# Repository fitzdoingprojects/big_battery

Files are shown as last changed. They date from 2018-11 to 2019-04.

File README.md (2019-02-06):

# big_battery
Charge Controller for 12 cell Lifepo4 batteries

Output voltage can be adjusted between 0 and 110% with voltage between TRM and -S on CN1:
Output Voltage = (Voltage between TMR and -S / 2.5) * 5V

Output current can be measured between CB adn -S on either CN1 or CN2.
Ouput current: 1Vcb = 0A, 0Vcb = 50A, -1Vcb = 100A
	Iout = 50 * (-Vcb + 1)
Required input impedance > 500kOh
Max current 120A ???

Circuit:
	Set TRM to default ouput of 4.2V, allow output range of 0 to 4.2V
	Invert and shift current sense from -1 to 2V, to 0V to 2.4V
	Over current feedback, with max current and trickle current
	Isolated signalling, either capacitive or dedicated IC

TESTING:
	* Double check default output voltage of 4.2V
	* Double check current graph/equation

Results:
    With 0 current, CB measuers 1.221V
    1A , 1.5V
    2A, 1.13
	3A, 1.098
	4A, 1.069
	5A, 1.04
SHOULD REQUIRE DIRECT TURN OFF?

BOARD REVISION:
 * ADD 3.3V test point
 * ADD potentiometer for adjusting current and voltage set points
 * change plus and minus inputs on op-amp B (because CB voltage decreases as voltage rises)
 * add reverse input protection diode
 * make sure trickle disable is pulled low
 * add some leds for signalling

 HOW FLASH EFM8 MCU:
 
 https://www.silabs.com/community/mcu/8-bit/knowledge-base.entry.html/2015/06/08/how_to_use_efm8_star-8aHu
 https://www.allaboutcircuits.com/projects/custom-pcb-design-with-an-efm8-microcontroller/

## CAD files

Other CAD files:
firmware/big_battery/Keil 8051 v9.53 - Debug/src/big_battery_main.OBJ
firmware/big_battery/Keil 8051 v9.53 - Debug/src/InitDevice.OBJ
mech/battery_terminal.SLDPRT
mech/power_supply_base.SLDPRT
firmware/big_battery/Keil 8051 v9.53 - Debug/src/SILABS_STARTUP.OBJ
mech/battery_terminal.DXF
mech/power_supply_base.DXF

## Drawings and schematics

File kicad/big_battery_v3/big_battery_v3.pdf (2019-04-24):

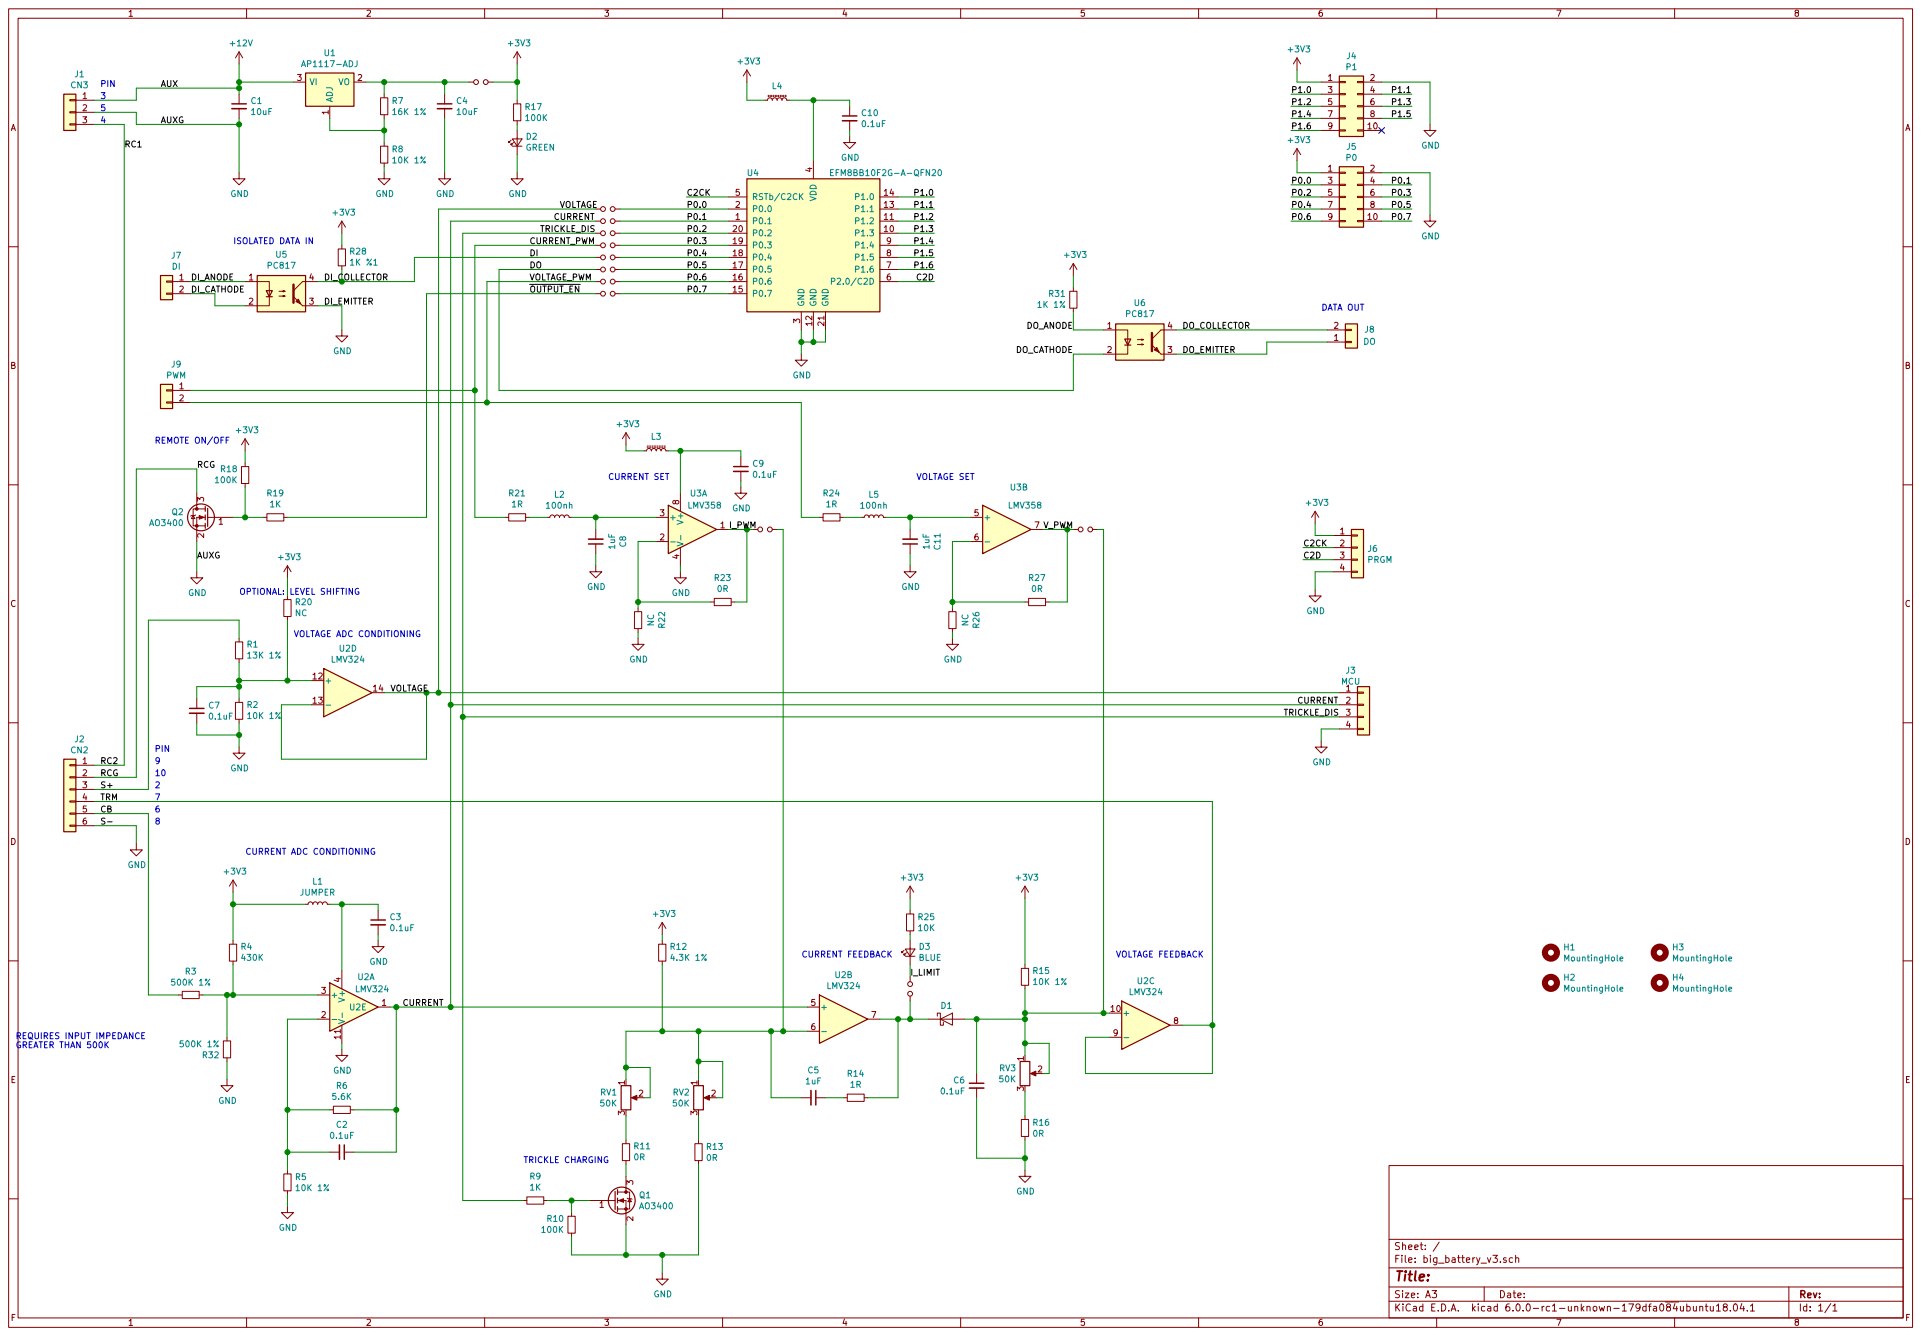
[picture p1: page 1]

J9 PWM
REMOTE ON/OFF PIN
100K GND

TRICKLE_DIS 3

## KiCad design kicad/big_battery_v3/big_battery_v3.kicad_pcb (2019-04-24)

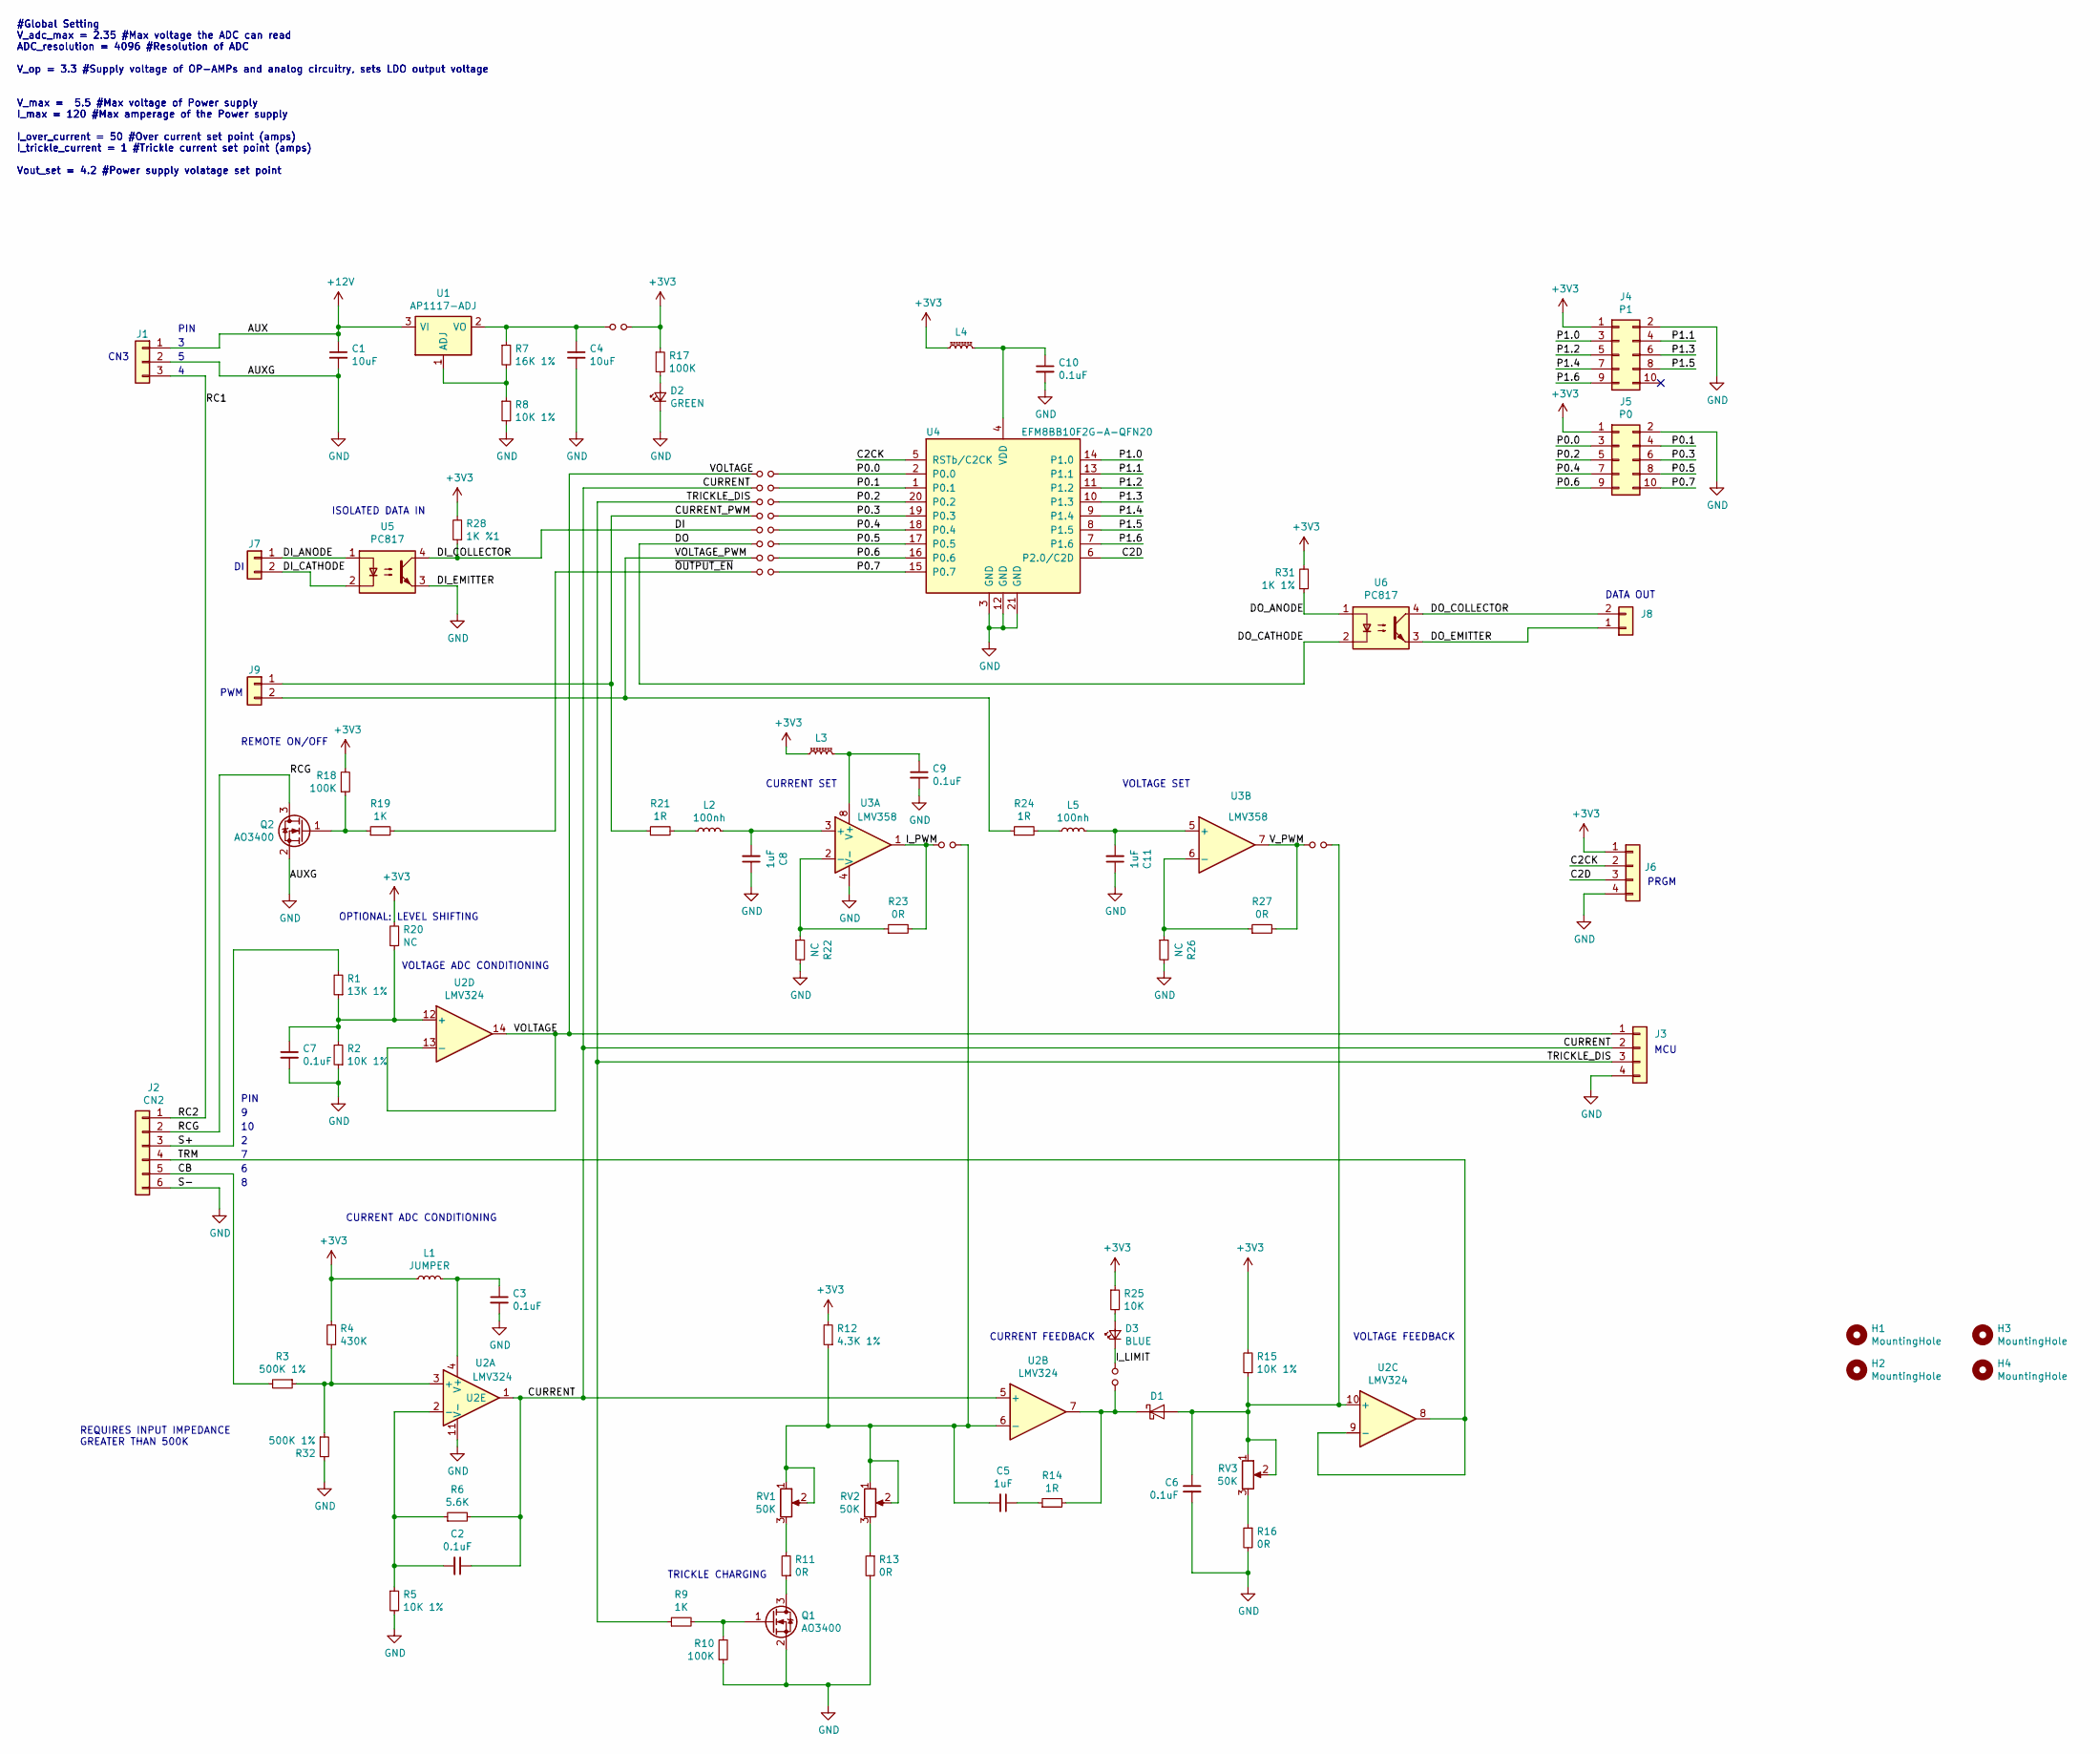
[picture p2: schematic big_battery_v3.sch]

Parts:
C1, C4: 10uF; C_0603_1608Metric_Pad1.05x0.95mm_HandSolder
C2, C3, C6, C7, C9, C10: 0.1uF; C_0603_1608Metric_Pad1.05x0.95mm_HandSolder
C5, C8, C11: 1uF; C_0603_1608Metric_Pad1.05x0.95mm_HandSolder
D1: D_Schottky_Small; D_SOD-323_HandSoldering
D2: GREEN; LED_0603_1608Metric_Pad1.05x0.95mm_HandSolder
D3: BLUE; LED_0603_1608Metric_Pad1.05x0.95mm_HandSolder
H1, H2, H3, H4: MountingHole; MountingHole_2.2mm_M2
J1: CONN; JST_EH_B03B-EH-A_1x03_P2.50mm_Vertical
J2: CN2; JST_EH_B06B-EH-A_1x06_P2.50mm_Vertical
J3, J6: CONN; JST_EH_B04B-EH-A_1x04_P2.50mm_Vertical
J4: P1; Multicomp_MC9A12-1034_2x05_P2.54mm_Vertical
J5: P0; Multicomp_MC9A12-1034_2x05_P2.54mm_Vertical
J7, J8, J9: CONN; JST_EH_B02B-EH-A_1x02_P2.50mm_Vertical
JP1, JP2, JP3, JP4, JP5, JP6, JP7, JP8, JP9, JP10, JP11, JP12: Jumper_NO_Small; SolderJumper-2_P1.3mm_Open_RoundedPad1.0x1.5mm
L1: JUMPER; L_0603_1608Metric_Pad1.05x0.95mm_HandSolder
L2, L5: 100nh; L_0603_1608Metric_Pad1.05x0.95mm_HandSolder
L3, L4: L_Core_Ferrite_Small; L_0603_1608Metric_Pad1.05x0.95mm_HandSolder
Q1, Q2: AO3400; SOT-23_Handsoldering
R1: 13K 1%; R_0603_1608Metric_Pad1.05x0.95mm_HandSolder
R2, R5, R8, R15: 10K 1%; R_0603_1608Metric_Pad1.05x0.95mm_HandSolder
R3, R32: 500K 1%; R_0603_1608Metric_Pad1.05x0.95mm_HandSolder
R4: 430K; R_0603_1608Metric_Pad1.05x0.95mm_HandSolder
R6: 5.6K; R_0603_1608Metric_Pad1.05x0.95mm_HandSolder
R7: 16K 1%; R_0603_1608Metric_Pad1.05x0.95mm_HandSolder
R9, R19: 1K; R_0603_1608Metric_Pad1.05x0.95mm_HandSolder
R10, R17, R18: 100K; R_0603_1608Metric_Pad1.05x0.95mm_HandSolder
R11, R13, R16, R23, R27: 0R; R_0603_1608Metric_Pad1.05x0.95mm_HandSolder
R12: 4.3K 1%; R_0603_1608Metric_Pad1.05x0.95mm_HandSolder
R14, R21, R24: 1R; R_0603_1608Metric_Pad1.05x0.95mm_HandSolder
R20, R22, R26: NC; R_0603_1608Metric_Pad1.05x0.95mm_HandSolder
R25: 10K; R_0603_1608Metric_Pad1.05x0.95mm_HandSolder
R28: 1K %1; R_0603_1608Metric_Pad1.05x0.95mm_HandSolder
R31: 1K 1%; R_0603_1608Metric_Pad1.05x0.95mm_HandSolder
RV1, RV2, RV3: 50K; Potentiometer_Bourns_3296W_Vertical
U1: AP1117-ADJ; SOT-223-3_TabPin2
U2: LMV324; SOIC-14_3.9x8.7mm_P1.27mm
U3: LMV358; SOIC-8_3.9x4.9mm_P1.27mm
U4: EFM8BB10F2G-A-QFN20; SiliconLabs_QFN-20-1EP_3x3mm_P0.5mm_ThermalVias
U5, U6: PC817; DIP-4_W7.62mm

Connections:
+3V3: J4.1, J5.1, J6.1, JP1.2, L1.1, L3.1, L4.1, R4.2, R12.2, R15.2, R17.1, R18.2, R20.2, R25.1, R28.2, R31.2
+12V: C1.1, J1.1, U1.3 (VI)
/C2CK: J6.2, U4.5 (RSTb/C2CK)
/C2D: J6.3, U4.6 (P2.0/C2D)
/CB: J2.5, R3.2
/CURRENT: C2.1, J3.2, JP3.1, R6.2, U2.1, U2.5 (+)
/CURRENT_PWM: J9.1, JP5.1, R21.1
/DI: JP6.1, R28.1, U5.4
/DI_ANODE: J7.1, U5.1
/DI_CATHODE: J7.2, U5.2
/DO: JP7.1, U6.2
/DO_ANODE: R31.1, U6.1
/DO_COLLECTOR: J8.2, U6.4
/DO_EMITTER: J8.1, U6.3
/I_LIMIT: D3.1 (K), JP9.2
/I_PWM: JP8.1, R23.2, U3.1
/P0.0: J5.3, JP2.2, U4.2 (P0.0)
/P0.1: J5.4, JP3.2, U4.1 (P0.1)
/P0.2: J5.5, JP4.2, U4.20 (P0.2)
/P0.3: J5.6, JP5.2, U4.19 (P0.3)
/P0.4: J5.7, JP6.2, U4.18 (P0.4)
/P0.5: J5.8, JP7.2, U4.17 (P0.5)
/P0.6: J5.9, JP11.2, U4.16 (P0.6)
/P0.7: J5.10, JP12.2, U4.15 (P0.7)
/P1.0: J4.3, U4.14 (P1.0)
/P1.1: J4.4, U4.13 (P1.1)
/P1.2: J4.5, U4.11 (P1.2)
/P1.3: J4.6, U4.10 (P1.3)
/P1.4: J4.7, U4.9 (P1.4)
/P1.5: J4.8, U4.8 (P1.5)
/P1.6: J4.9, U4.7 (P1.6)
/RC1: J1.3, J2.1
/RCG: J2.2, Q2.3 (D)
/S+: J2.3, R1.2
/TRICKLE_DIS: J3.3, JP4.1, R9.1
/TRM: J2.4, U2.8, U2.9 (-)
/VOLTAGE: J3.1, JP2.1, U2.13 (-), U2.14
/VOLTAGE_PWM: J9.2, JP11.1, R24.1
/V_PWM: JP10.1, R27.2, U3.7
/~OUTPUT_EN: JP12.1, R19.2
GND: C1.2, C3.2, C4.2, C6.2, C7.2, C8.1, C9.2, C10.2, C11.1, D2.1 (K), J1.2, J2.6, J3.4, J4.2, J5.2, J6.4, Q1.2 (S), Q2.2 (S), R2.1, R5.2, R8.2, R10.1, R13.2, R16.2, R22.2, R26.2, R32.2, U2.11 (V-), U3.4 (V-), U4.3 (GND), U4.12 (GND), U4.21 (GND), U5.3
unnamed: C2.2, R5.1, R6.1, U2.2 (-)
unnamed: C3.1, L1.2, U2.4 (V+)
unnamed: C4.1, JP1.1, R7.1, U1.2 (VO)
unnamed: C5.1, R14.1
unnamed: C5.2, JP8.2, R12.1, RV1.1, RV1.2, RV2.1, RV2.2, U2.6 (-)
unnamed: C6.1, D1.2 (A), JP10.2, R15.1, RV3.1, RV3.2, U2.10 (+)
unnamed: C7.1, R1.1, R2.2, R20.1, U2.12 (+)
unnamed: C8.2, L2.2, U3.3 (+)
unnamed: C9.1, L3.2, U3.8 (V+)
unnamed: C10.1, L4.2, U4.4 (VDD)
unnamed: C11.2, L5.2, U3.5 (+)
unnamed: D1.1 (K), JP9.1, R14.2, U2.7
unnamed: D2.2 (A), R17.2
unnamed: D3.2 (A), R25.2
unnamed: L2.1, R21.2
unnamed: L5.1, R24.2
unnamed: Q1.1 (G), R9.2, R10.2
unnamed: Q1.3 (D), R11.1
unnamed: Q2.1 (G), R18.1, R19.1
unnamed: R3.1, R4.1, R32.1, U2.3 (+)
unnamed: R7.2, R8.1, U1.1 (ADJ)
unnamed: R11.2, RV1.3
unnamed: R13.1, RV2.3
unnamed: R16.1, RV3.3
unnamed: R22.1, R23.1, U3.2 (-)
unnamed: R26.1, R27.1, U3.6 (-)

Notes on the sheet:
REQUIRES INPUT IMPEDANCE GREATER THAN 500K
#Global Setting V_adc_max = 2.35 #Max voltage the ADC can read ADC_resolution = 4096 #Resolution of ADC V_op = 3.3 #Supply voltage of OP-AMPs and analog circuitry, sets LDO output voltage V_max = 5.5 #Max voltage of Power supply I_max = 120 #Max amperage of the Power supply I_over_current = 50 #Ove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
OPTIONAL: LEVEL SHIFTING
CURRENT SET
VOLTAGE SET
VOLTAGE ADC CONDITIONING
CURRENT ADC CONDITIONING
CURRENT FEEDBACK
VOLTAGE FEEDBACK
TRICKLE CHARGING
ISOLATED DATA IN
REMOTE ON/OFF
PIN
DATA OUT
CN3
PWM
PRGM
MCU

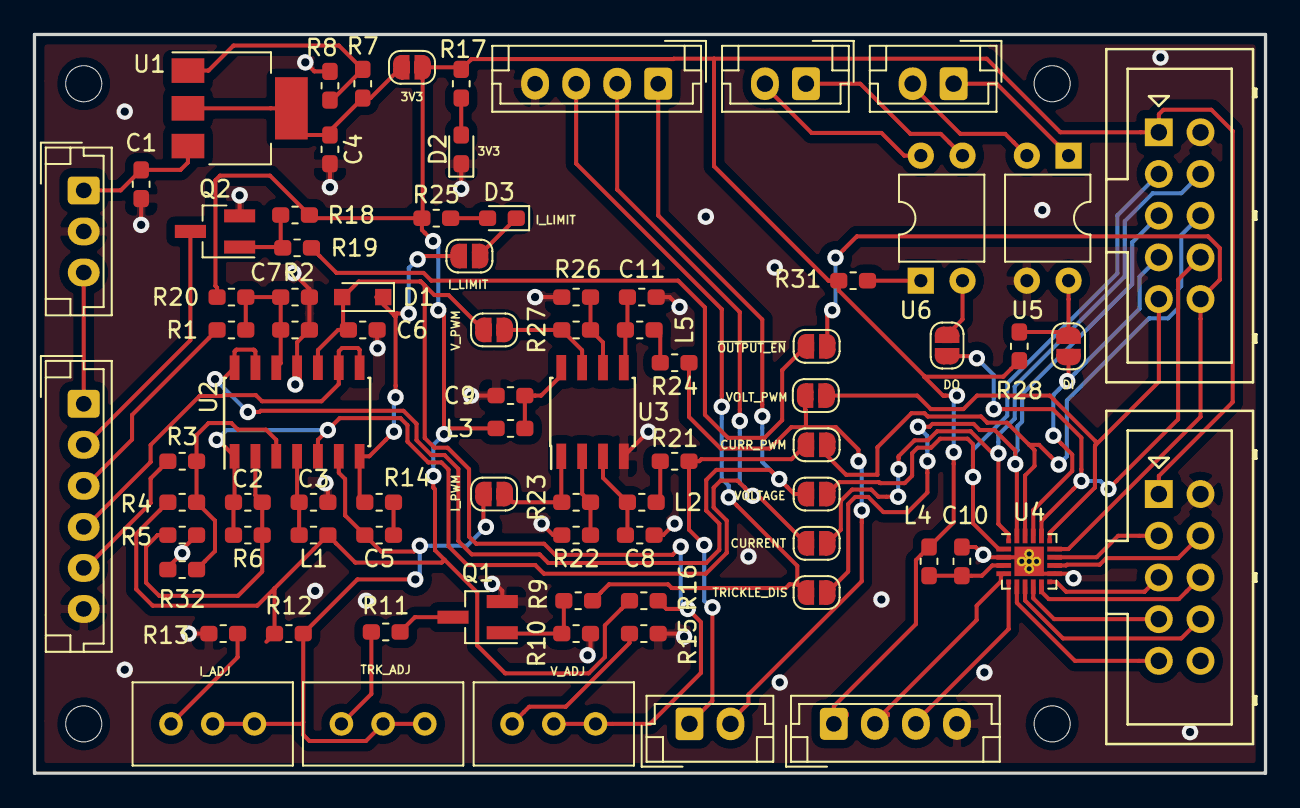
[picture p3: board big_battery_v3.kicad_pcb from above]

Board: 2 copper layers, 75.0 x 45.0 mm, 85 parts (0 on the bottom side), 67 nets.

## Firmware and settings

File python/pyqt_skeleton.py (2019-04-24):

import sys, time, serial
from struct import pack, unpack
import threading
from PyQt5 import QtCore, QtGui, QtWidgets
from test1 import Ui_Form
 
class MyFirstGuiProgram(Ui_Form):
    def __init__(self, dialog, comm):
        Ui_Form.__init__(self)
        self.setupUi(dialog)
        self.comm = comm
        self.connectButton.clicked.connect(self.connect)
        self.voltageButton.clicked.connect(self.setVoltage)
        self.voltageSlider.valueChanged.connect(self.convertVoltage)
        self.currentButton.clicked.connect(self.setCurrent)
        self.currentSlider.valueChanged.connect(self.convertCurrent)
        self.tricklecheckBox.stateChanged.connect(self.trickle)
        self.outputcheckBox.stateChanged.connect(self.output)
        self.pollButton.clicked.connect(self.poll)

    def connect(self):
        if not self.comm.connected:
            if(self.comm.open(self.seriallineEdit.text())):
                self.connected = True
                self.seriallineEdit.setEnabled(False)
                self.connectButton.setText("DISCONNECT")
                self.voltageButton.setEnabled(True)
                self.voltagelineEdit.setEnabled(True)
                self.currentButton.setEnabled(True)
                self.currentlineEdit.setEnabled(True)
                self.tricklecheckBox.setEnabled(True)
                self.outputcheckBox.setEnabled(True)
                self.pollButton.setEnabled(True)
                self.currentButton.setEnabled(True)
                self.currentButton.setEnabled(True)
                self.comHistory.appendPlainText("Connected: " + self.comm.dev)
            else:
                self.connectButton.setText("CONNECT")
                self.comHistory.appendPlainText("Failed to open: " + self.comm.dev)
        else:
            self.comm.close()
            self.connectButton.setText("CONNECT")
            self.seriallineEdit.setEnabled(True)
            self.voltageButton.setEnabled(False)
            self.voltagelineEdit.setEnabled(False)
            self.currentButton.setEnabled(False)
            self.currentlineEdit.setEnabled(False)
            self.tricklecheckBox.setEnabled(False)
            self.outputcheckBox.setEnabled(False)
            self.pollButton.setEnabled(False)
            self.currentButton.setEnabled(False)
            self.currentButton.setEnabled(False)
            self.comHistory.appendPlainText("Disconnected")
        
    def setVoltage(self):
        setV = self.voltagespinBox.value()
        cmd, out = self.comm.setVoltage('1', setV)
        self.updateCommandLine(cmd, out)
        
    def convertVoltage(self, val):
        self.voltagelineEdit.setText(str(val))

    def setCurrent(self):
        setC = self.currentSpinBox.value()
        cmd, out = self.comm.setCurrent('1', setC)
        self.updateCommandLine(cmd, out)

    def convertCurrent(self, val):
            self.currentlineEdit.setText(str(val))

    def trickle(self, state):
        cmd, out = self.comm.setTrickle('1', 1 if state else 0)
        self.updateCommandLine(cmd, out)

    def output(self, state):
        cmd, out = self.comm.setEnable('1', 1 if state else 0)
        self.updateCommandLine(cmd, out)

    def poll(self):
        cmd, out = self.comm.getVoltage('1')
        self.updateCommandLine(cmd, out)
        if out is not None:
            self.vadclineEdit.setText(str(out[2] * 0.0013195800781249998))
            self.vadclcdNumber.display(hex(out[2]))
        
        cmd, out = self.comm.getCurrent('1')
        self.updateCommandLine(cmd, out)
        if out is not None:
            self.iadclineEdit.setText(str((out[2] * -0.05815991633124628) + 240.93023255813955))
            self.iadclcdNumber.display(hex(out[2]))

        cmd, out = self.comm.getTemperature('1')
        self.updateCommandLine(cmd, out)
        if out is not None:
            self.tadclineEdit.setText(str(out[2]))
            self.tadclcdNumber.display(hex(out[2]))

    def updateCommandLine(self, cmd, out):
        self.comHistory.appendPlainText(">> " + str(cmd))
        self.comHistory.appendPlainText("<< " + str(out))

class BigBatteryComm():
    def __init__(self):
        self.connected = False

    def open(self, dev):
        self.dev = dev
        try:
            self.ser = serial.Serial(dev, 4800, timeout = 1) # ttyACM1 for Arduino board
            self.connected = True
            return True
        except:
            self.connected = False
            return False

    def close(self):
        self.connected = False
        self.ser.close()

    def setVoltage(self, devNum, val):
        return self.setVal(devNum, "TV", val)

    def setCurrent(self, devNum, val):
        return self.setVal(devNum, "TI", val)

    def setTrickle(self, devNum, val):
        return self.setVal(devNum, "TT", val)
    
    def setEnable(self, devNum, val):
        return self.setVal(devNum, "TE", val)

    def setVal(self, devNum, command , val):
        sent =  bytes(devNum, 'utf-8'), bytes(command, 'utf-8'), int(val), bytes('X', 'utf-8')
        cmd = pack('>c2sHc', bytes(devNum, 'utf-8'), bytes(command, 'utf-8'), int(val), bytes('X', 'utf-8'))
        try: 
            self.ser.write(cmd)
            out = self.ser.read(7)
            out = unpack('>ccH3s', out)
            self.ser.flush() #flush the buffer
        except:
            out = None
        return sent, out

    def getVoltage(self, devNum):
        return self.getVal(devNum, "RV")

    def getCurrent(self, devNum):
        return self.getVal(devNum, "RI")

    def getTemperature(self, devNum):
        return self.getVal(devNum, "RT")

    def getVal(self, devNum, command):
        sent = (bytes(devNum, 'utf-8'), bytes(command, 'utf-8'), bytes('X', 'utf-8'))
        cmd = pack('c2sc', bytes(devNum, 'utf-8'), bytes(command, 'utf-8'), bytes('X', 'utf-8'))
        try: 
            self.ser.write(cmd)
            out = self.ser.read(7)
            out = unpack('>ccH3s', out)
            print(out)
            self.ser.flush() #flush the buffer
        except:
            out = None
        return sent, out

    




if __name__ == '__main__':
    app = QtWidgets.QApplication(sys.argv)
    dialog = QtWidgets.QDialog()
    comm = BigBatteryComm()
    prog = MyFirstGuiProgram(dialog, comm)
    
    dialog.show()
    sys.exit(app.exec_())

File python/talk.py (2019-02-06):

import serial
import time

ser = serial.Serial('/dev/ttyUSB0', 9600, timeout = 1) # ttyACM1 for Arduino board

readOut = 0   #chars waiting from laser range finder

print ("Starting up")
connected = False
commandToSend = "1RVX" # get the distance in mm

while True:
    while True:
        cmd = input(">> ")
        if cmd == 'exit':
            ser.close()
            exit()
        else:
            ser.write(cmd.encode('ascii'))
            time.sleep(2)  
        try:
            print ("Attempt to Read")
            while
            readOut = ser.readline().decode('ascii')
            print ("Reading: ", readOut) 
            break
        except:
            pass
    print ("Restart")
    ser.flush() #flush the buffer

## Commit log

2018-10-27 mech, schematic, script for component values, and datasheet
    [battery_terminal.DXF, battery_terminal.SLDPRT, big_battery.kicad_pcb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]
2018-10-30 fixes component selection script
    [big_battery.sch]
2018-11-14 pretty much working board, requires some bodges on the op-amp and extra potentiometers
    [big_battery.kicad_pcb, big_battery.sch]
2018-11-14 adds library schematic rescue .dcm file
2018-11-14 attempt to fix kicad symbol library
    [big_battery.sch]
2018-11-22 adds big battery v2.0
    [big_battery.kicad_pcb, big_battery.sch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]
2018-11-23 fixing up silkscreen
    [big_battery.kicad_pcb, big_battery.sch]
2018-11-28 final gerbers sent out
    [big_battery.kicad_pcb, big_battery.sch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]
2018-11-28 adds gerbers and rescue libs
    [big_battery-B.Cu.gbl, big_battery-B.Mask.gbs, big_battery-B.SilkS.gbo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]
2018-12-11 adds first firmware version
    [InitDevice.OBJ, SILABS_STARTUP.OBJ, big_battery.sch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]
2018-12-11 got uart working
    [InitDevice.OBJ, SILABS_STARTUP.OBJ, big_battery_main.OBJ]
2018-12-12 got pwm working
    [InitDevice.OBJ, SILABS_STARTUP.OBJ, big_battery_main.OBJ]
2018-12-12 got gpio working
    [InitDevice.OBJ, SILABS_STARTUP.OBJ, big_battery.sch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]
2018-12-19 got most of uart communication working
    [InitDevice.OBJ, SILABS_STARTUP.OBJ, big_battery_main.OBJ]
2018-12-19 tested rest of uart communication
    [InitDevice.OBJ, SILABS_STARTUP.OBJ, big_battery_main.OBJ]
2018-12-19 updated schematic to include bodge wires
    [InitDevice.OBJ, SILABS_STARTUP.OBJ, big_battery.sch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]
2019-02-06 made a gui interface
    [InitDevice.OBJ, big_battery_main.OBJ]
2019-02-07 saving workingish serial communication before rewrite
    [InitDevice.OBJ, SILABS_STARTUP.OBJ, big_battery_main.OBJ]
2019-02-07 cleans up communication gui code
    [InitDevice.OBJ, SILABS_STARTUP.OBJ, big_battery_main.OBJ]
2019-04-24 adds big battery v3
    [InitDevice.OBJ, big_battery_main.OBJ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]
2020-02-26 updates interactive bom for big_battery3
